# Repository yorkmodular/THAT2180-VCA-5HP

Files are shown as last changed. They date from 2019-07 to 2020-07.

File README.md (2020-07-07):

## York Modular THAT2180 VCA

I've done more than my fair share of lo-fi VCAs in the past, so here's one with a bit more in the way of 'fi'.

Unlike some others, this module is built around the THAT2180 Blackmer cell IC - I find it easier to use, and less prone to self-destruction, than the V2164.

This is a 100% through-hole build - there are a couple of different versions of the THAT2180 (A and B) but unless you're looking for insanely low levels of THD the C variant gives the best bang for the buck.

In addition there are a pair of signal inputs (unattenuated) and a pair of control-voltage inputs with associated attenuators. Prototype versions of this module had one attenuated and one unattenuated CV channel, but since the 2180 is pretty sensitive where control voltages are concerned I decided to add an attenuator to the second CV channel too - even so, it's possible to get some _very_ cool sounding distortion out of it with the levels turned up.

The included parts pretty much reflect a datasheet build, but if you know what you're doing then there's scope for a bit of tweaking here and there (in particular, the CV input stage)

### Construction notes

- The THAT2180 is an SIL (single inline) IC - these are pretty uncommon but really no different from the DIL ICs you may be used to. The footprint on the PCB will have a dot at one end corresponding to pin 1; the notch in the IC should be at this end.
- As mentioned above, there are different variants of the THAT2180. The kit will contain the C variant - if you feel the need to use the A or B variant then go ahead; they're all interchangeable but the A and B variants are pretty expensive.
- The op-amp in the circuit is acting as both an amplifier and a buffer. I supply a TL072/082 by default and these will do the job admirably. If you want to use a 'proper' audio op-amp then make sure it is pin-compatible with the TL0x2 series. Most dual audio op-amps (eg. NE5532) are, but double-check first.
- **IMPORTANT**: Fit the trimmer pot _before_ you solder the level pots and jacks in place. Trust me on this ;-)

### Basic setup

Unless you strike it _extremely_ lucky then chances are you're going to have to do a bit of tweaking once you've completed the build. In a nutshell, you'll probably want no output from the VCA when the control voltage is 0V.

Fortunately, there's a simple way to achieve this:

- Plug an audio source (VCO, whatever) into one or both of the signal inputs - it doesn't matter which.
- Turn the CV attenuators fully counter-clockwise
- Plug the output into either an oscilloscope (preferred) or a suitable speaker.
- **If you're using an oscilloscope**, adjust the trimmer pot on the module until the output is 0V (or whatever value you prefer). 
- If you're working by ear:
-- **If there's an audible output with zero CV**, adjust the trimmer until you can no longer hear anything.
-- **If there isn't an audible output**, adjust the trimmer until you can hear something and _then_ readjust until the signal is no longer audible.

There are undoubtedly fancier ways of achieving the same result, but this Works For Me. 

Be aware that you _will_ get signal distortion if you use particularly hot CVs - the two attenuator pots are log taper, which should give you a fair degree of control over the CV levels (if you'd prefer linear taper, go ahead and use them instead)

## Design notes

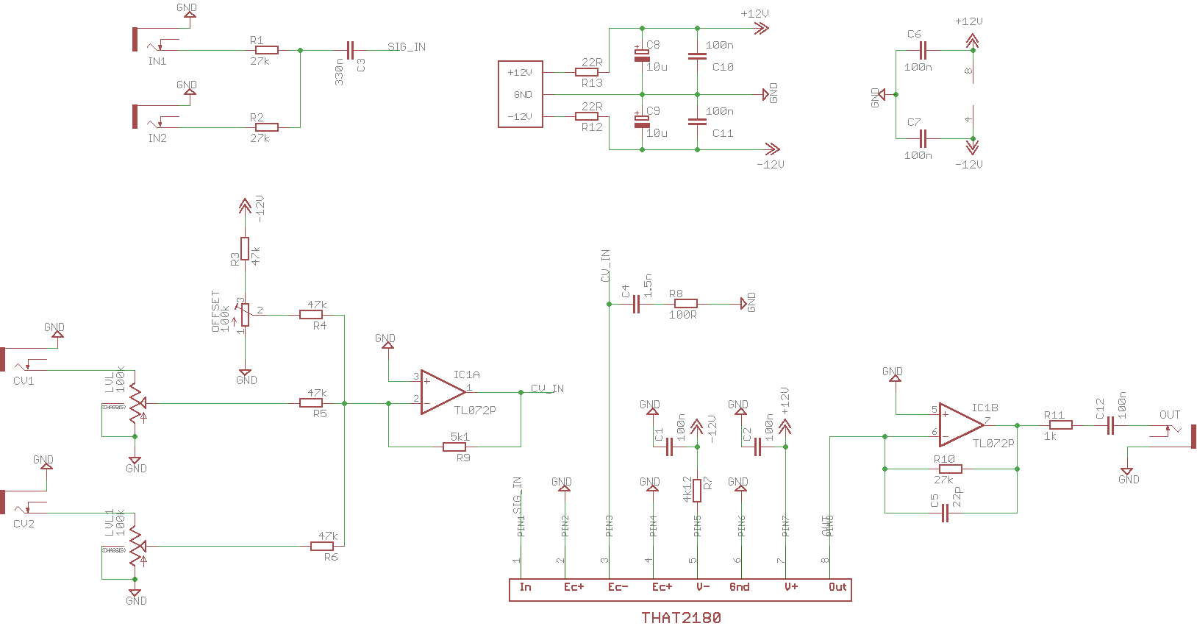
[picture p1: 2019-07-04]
that2180-vca-schematic.png

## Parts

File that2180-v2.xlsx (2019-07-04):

Qty | Value | Device | Package | Parts | Description
1 | 1.5n | C-EU025-025X050 | C025-025X050 | C4 | CAPACITOR, European symbol
1 | 100R | R-EU_0207/2V | 0207/2V | R8 | RESISTOR, European symbol
6 | 100n | C-EU025-025X050 | C025-025X050 | C1, C2, C6, C7, C10, C11 | CAPACITOR, European symbol
1 | 100n | C-EU050-025X075 | C050-025X075 | C12 | CAPACITOR, European symbol
2 | 10u | CPOL-EUE2.5-5 | E2,5-5 | C8, C9 | POLARIZED CAPACITOR, European symbol
1 | 1k | R-EU_0207/2V | 0207/2V | R11 | RESISTOR, European symbol
2 | 22R | R-EU_0207/2V | 0207/2V | R12, R13 | RESISTOR, European symbol
1 | 22p | C-EU025-025X050 | C025-025X050 | C5 | CAPACITOR, European symbol
3 | 27k | R-EU_0207/2V | 0207/2V | R1, R2, R10 | RESISTOR, European symbol
1 | 330n | C-EU050-025X075 | C050-025X075 | C3 | CAPACITOR, European symbol
4 | 47k | R-EU_0207/2V | 0207/2V | R3, R4, R5, R6 | RESISTOR, European symbol
1 | 4k12 | R-EU_0207/2V | 0207/2V | R7 | RESISTOR, European symbol
2 | 100k | 9MM_SNAP-IN_POT_CHASSIS | 9MM_SNAP-IN_POT | LVL, LVL1 | Log taper recommended, but linear will work too.
1 | 100k | R-TRIMM3296W | RTRIM3296W | OFFSET | Offset trimmer – Bourns 3296W or equivalent.
1 | 5k1 | R-EU_0207/2V | 0207/2V | R9 | RESISTOR, European symbol
1 | EURO_POWER_LOCK | EURO_POWER_LOCK | EURO_PWR_HEADER_LOCK | LOCK1
1 | IC2 | THAT2180 | SIP8 | U$1 | THAT Corporations 2180 VCA
5 | THONKICONNNEW | THONKICONNNEW | WQP-PJ301M-12_JACK | CV1, CV2, IN1, IN2, OUT | 3.5mm socket for Eurorack modular synths
1 | TL072P | TL072P | DIL08 | IC1 | OP AMP
 |  |  |  |  | Variable resistor values are not set in stone – 50k will work instead of 100k, for example.

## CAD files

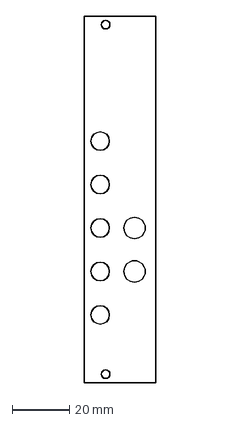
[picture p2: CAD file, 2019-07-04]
2180vca-v2-blank.dxf
25.1 x 128.4 mm

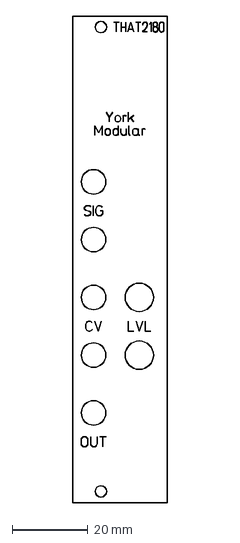
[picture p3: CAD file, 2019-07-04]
2180vca-v2.dxf
25.1 x 128.4 mm

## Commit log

2019-07-04 Panel files
    [2180vca-v2-blank.dxf, 2180vca-v2.dxf]
2019-07-04 BOM file
    [that2180-v2.xlsx]
